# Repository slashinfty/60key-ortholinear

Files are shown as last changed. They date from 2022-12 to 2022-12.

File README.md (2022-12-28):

# 60key-ortholinear
A 5x12 ortholinear keyboard using a Raspberry Pi Pico

## Bill of Materials
* Case (see below)
* PCB (see below)
* Raspberry Pi Pico (with separate pin headers)
* 60 switches (I used Brown Gateron)
* 60 1N4148 diodes
* 60 1u keycaps

### Case
I have 3D designed a case specifically for this keyboard. It requires 4 M2.5x12mm screws.

### PCB
Gerber files have been uploaded to this repository, and a service such as JLCPCB can be used to order PCBs.

## Assembly
Complete these steps in order:
* Place the pin headers on the back, and apply solder on the front. Cut the excess flush with the PCB.
* Place diodes on the back, and apply solder on the front. Cut the excess flush with the PCB.
* Insert switches to the front of the case, mindful of orientation with the PCB.
* Place the PCB onto the switches, and apply solder on the back.
* Place the Raspberry Pi Pico on the pin headers and apply solder.
* Place the two halves of the case together and secure using screws.
* Place keycaps on switches.

## Code
First, [install CircuitPython](https://learn.adafruit.com/welcome-to-circuitpython/installing-circuitpython). Then, copy `keyboard.py` to the Raspberry Pi Pico.

The layout of the keyboard can be viewed [here](http://www.keyboard-layout-editor.com/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'%3B&@=Shift&=Z&=X&=C&=V&=B&=N&=M&_a:4%3B&=%0A%0A%0A-%0A%0A%0A%0A%0A%0A,&=%0A%0A%0A%2F=%0A%0A%0A%0A%0A%0A.&=%0A%0A%0A%5B%0A%0A%0A%0A%0A%0A%2F%2F&=%0A%0A%0A%5D%0A%0A%0A%0A%0A%0A%5C%3B&@_a:7%3B&=Prt%20Sc&=Ctrl&=Super&=Alt&=Fn%201&=&=&=Fn%202&_a:4%3B&=%0A%0A%0AH%0A%0A%0A%0A%0A%0A%2F&larr%2F%3B&=%0A%0A%0APD%0A%0A%0A%0A%0A%0A%2F&darr%2F%3B&=%0A%0A%0APU%0A%0A%0A%0A%0A%0A%2F&uarr%2F%3B&=%0A%0A%0AE%0A%0A%0A%0A%0A%0A%2F&rarr%2F).

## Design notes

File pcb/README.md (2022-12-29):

Raspberry Pi Pico KiCad files available [here](https://github.com/ncarandini/KiCad-RP-Pico).

Keyboard switch KiCad files available [here](https://github.com/perigoso/keyswitch-kicad-library).

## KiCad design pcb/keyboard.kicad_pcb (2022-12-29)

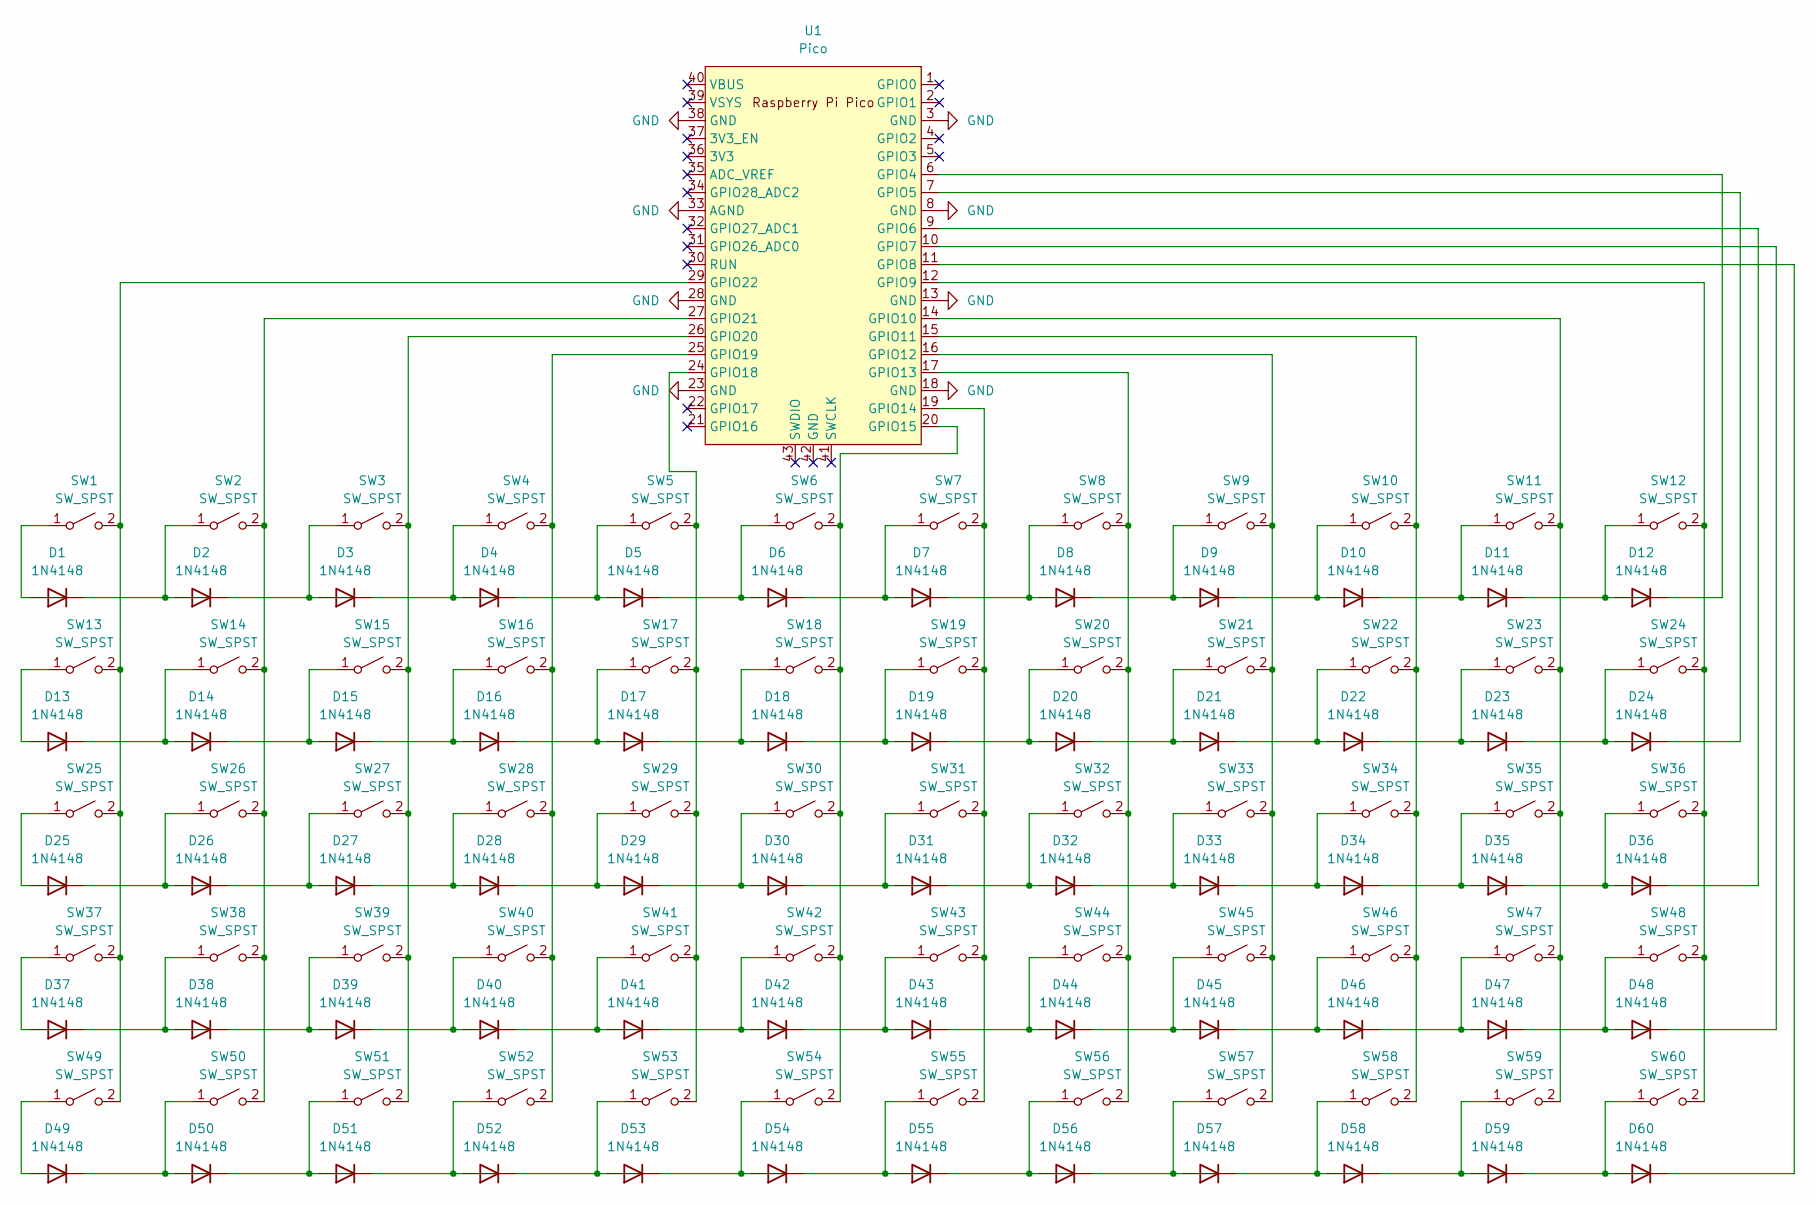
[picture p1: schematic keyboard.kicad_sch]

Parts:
D1, D2, D3, D4, D5, D6, D7, D8, D9, D10, D11, D12, D13, D14, D15, D16, D17, D18, D19, D20, D21, D22, D23, D24, D25, D26, D27, D28, D29, D30, D31, D32, D33, D34, D35, D36, D37, D38, D39, D40, D41, D42, D43, D44, D45, D46, D47, D48, D49, D50, D51, D52, D53, D54, D55, D56, D57, D58, D59, D60: 1N4148; D_DO-35_SOD27_P7.62mm_Horizontal
SW1, SW2, SW3, SW4, SW5, SW6, SW7, SW8, SW9, SW10, SW11, SW12, SW13, SW14, SW15, SW16, SW17, SW18, SW19, SW20, SW21, SW22, SW23, SW24, SW25, SW26, SW27, SW28, SW29, SW30, SW31, SW32, SW33, SW34, SW35, SW36, SW37, SW38, SW39, SW40, SW41, SW42, SW43, SW44, SW45, SW46, SW47, SW48, SW49, SW50, SW51, SW52, SW53, SW54, SW55, SW56, SW57, SW58, SW59, SW60: SW_SPST; SW_Cherry_MX_1.00u_Plate
U1: Pico; RPi_Pico_SMD_TH

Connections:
GND: U1.3 (GND), U1.8 (GND), U1.13 (GND), U1.18 (GND), U1.23 (GND), U1.28 (GND), U1.33 (AGND), U1.38 (GND)
unnamed: D1.1 (K), D2.2 (A), SW2.1 (A)
unnamed: D1.2 (A), SW1.1 (A)
unnamed: D2.1 (K), D3.2 (A), SW3.1 (A)
unnamed: D3.1 (K), D4.2 (A), SW4.1 (A)
unnamed: D4.1 (K), D5.2 (A), SW5.1 (A)
unnamed: D5.1 (K), D6.2 (A), SW6.1 (A)
unnamed: D6.1 (K), D7.2 (A), SW7.1 (A)
unnamed: D7.1 (K), D8.2 (A), SW8.1 (A)
unnamed: D8.1 (K), D9.2 (A), SW9.1 (A)
unnamed: D9.1 (K), D10.2 (A), SW10.1 (A)
unnamed: D10.1 (K), D11.2 (A), SW11.1 (A)
unnamed: D11.1 (K), D12.2 (A), SW12.1 (A)
unnamed: D12.1 (K), U1.6 (GPIO4)
unnamed: D13.1 (K), D14.2 (A), SW14.1 (A)
unnamed: D13.2 (A), SW13.1 (A)
unnamed: D14.1 (K), D15.2 (A), SW15.1 (A)
unnamed: D15.1 (K), D16.2 (A), SW16.1 (A)
unnamed: D16.1 (K), D17.2 (A), SW17.1 (A)
unnamed: D17.1 (K), D18.2 (A), SW18.1 (A)
unnamed: D18.1 (K), D19.2 (A), SW19.1 (A)
unnamed: D19.1 (K), D20.2 (A), SW20.1 (A)
unnamed: D20.1 (K), D21.2 (A), SW21.1 (A)
unnamed: D22.1 (K), D23.2 (A), SW23.1 (A)
unnamed: D21.1 (K), D22.2 (A), SW22.1 (A)
unnamed: D23.1 (K), D24.2 (A), SW24.1 (A)
unnamed: D24.1 (K), U1.7 (GPIO5)
unnamed: D25.1 (K), D26.2 (A), SW26.1 (A)
unnamed: D25.2 (A), SW25.1 (A)
unnamed: D26.1 (K), D27.2 (A), SW27.1 (A)
unnamed: D27.1 (K), D28.2 (A), SW28.1 (A)
unnamed: D28.1 (K), D29.2 (A), SW29.1 (A)
unnamed: D29.1 (K), D30.2 (A), SW30.1 (A)
unnamed: D30.1 (K), D31.2 (A), SW31.1 (A)
unnamed: D31.1 (K), D32.2 (A), SW32.1 (A)
unnamed: D32.1 (K), D33.2 (A), SW33.1 (A)
unnamed: D33.1 (K), D34.2 (A), SW34.1 (A)
unnamed: D34.1 (K), D35.2 (A), SW35.1 (A)
unnamed: D35.1 (K), D36.2 (A), SW36.1 (A)
unnamed: D36.1 (K), U1.9 (GPIO6)
unnamed: D37.1 (K), D38.2 (A), SW38.1 (A)
unnamed: D37.2 (A), SW37.1 (A)
unnamed: D38.1 (K), D39.2 (A), SW39.1 (A)
unnamed: D39.1 (K), D40.2 (A), SW40.1 (A)
unnamed: D40.1 (K), D41.2 (A), SW41.1 (A)
unnamed: D41.1 (K), D42.2 (A), SW42.1 (A)
unnamed: D42.1 (K), D43.2 (A), SW43.1 (A)
unnamed: D43.1 (K), D44.2 (A), SW44.1 (A)
unnamed: D44.1 (K), D45.2 (A), SW45.1 (A)
unnamed: D45.1 (K), D46.2 (A), SW46.1 (A)
unnamed: D46.1 (K), D47.2 (A), SW47.1 (A)
unnamed: D47.1 (K), D48.2 (A), SW48.1 (A)
unnamed: D48.1 (K), U1.10 (GPIO7)
unnamed: D49.1 (K), D50.2 (A), SW50.1 (A)
unnamed: D50.1 (K), D51.2 (A), SW51.1 (A)
unnamed: D51.1 (K), D52.2 (A), SW52.1 (A)
unnamed: D52.1 (K), D53.2 (A), SW53.1 (A)
unnamed: D53.1 (K), D54.2 (A), SW54.1 (A)
unnamed: D54.1 (K), D55.2 (A), SW55.1 (A)
unnamed: D55.1 (K), D56.2 (A), SW56.1 (A)
unnamed: D56.1 (K), D57.2 (A), SW57.1 (A)
unnamed: D57.1 (K), D58.2 (A), SW58.1 (A)
unnamed: D58.1 (K), D59.2 (A), SW59.1 (A)
unnamed: D59.1 (K), D60.2 (A), SW60.1 (A)
unnamed: D60.1 (K), U1.11 (GPIO8)
unnamed: SW1.2 (B), SW13.2 (B), SW25.2 (B), SW37.2 (B), SW49.2 (B), U1.29 (GPIO22)
unnamed: SW2.2 (B), SW14.2 (B), SW26.2 (B), SW38.2 (B), SW50.2 (B), U1.27 (GPIO21)
unnamed: SW3.2 (B), SW15.2 (B), SW27.2 (B), SW39.2 (B), SW51.2 (B), U1.26 (GPIO20)
unnamed: SW4.2 (B), SW16.2 (B), SW28.2 (B), SW40.2 (B), SW52.2 (B), U1.25 (GPIO19)
unnamed: SW9.2 (B), SW21.2 (B), SW33.2 (B), SW45.2 (B), SW57.2 (B), U1.16 (GPIO12)
unnamed: SW10.2 (B), SW22.2 (B), SW34.2 (B), SW46.2 (B), SW58.2 (B), U1.15 (GPIO11)
unnamed: SW11.2 (B), SW23.2 (B), SW35.2 (B), SW47.2 (B), SW59.2 (B), U1.14 (GPIO10)
unnamed: SW12.2 (B), SW24.2 (B), SW36.2 (B), SW48.2 (B), SW60.2 (B), U1.12 (GPIO9)
unnamed: SW6.2 (B), SW18.2 (B), SW30.2 (B), SW42.2 (B), SW54.2 (B), U1.20 (GPIO15)
unnamed: SW7.2 (B), SW19.2 (B), SW31.2 (B), SW43.2 (B), SW55.2 (B), U1.19 (GPIO14)
unnamed: SW8.2 (B), SW20.2 (B), SW32.2 (B), SW44.2 (B), SW56.2 (B), U1.17 (GPIO13)
unnamed: D49.2 (A), SW49.1 (A)
unnamed: SW5.2 (B), SW17.2 (B), SW29.2 (B), SW41.2 (B), SW53.2 (B), U1.24 (GPIO18)

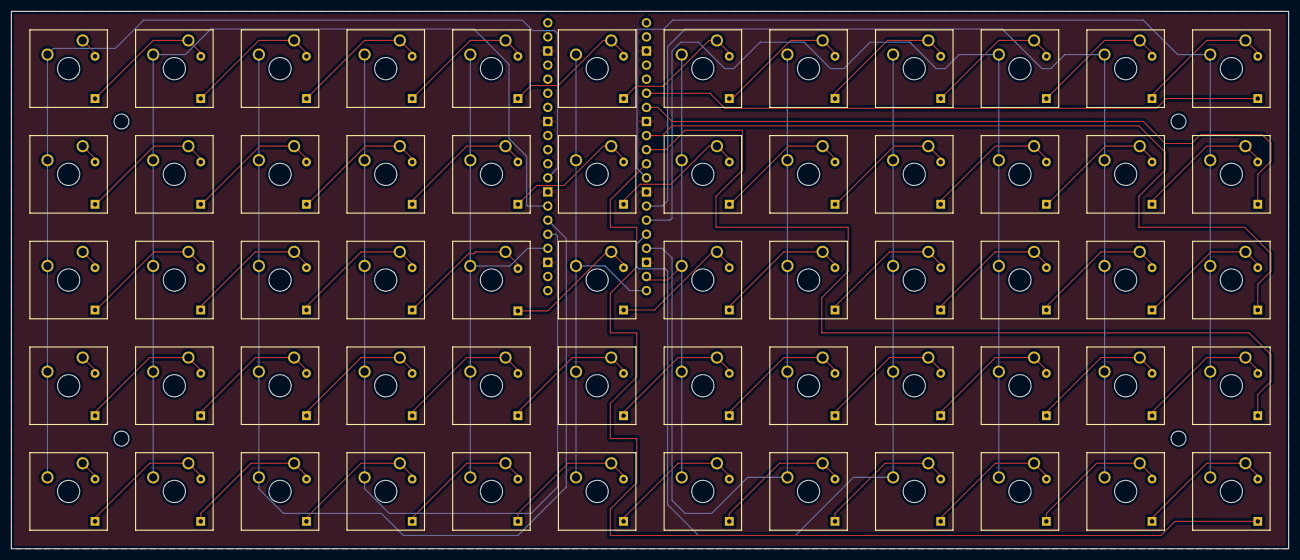
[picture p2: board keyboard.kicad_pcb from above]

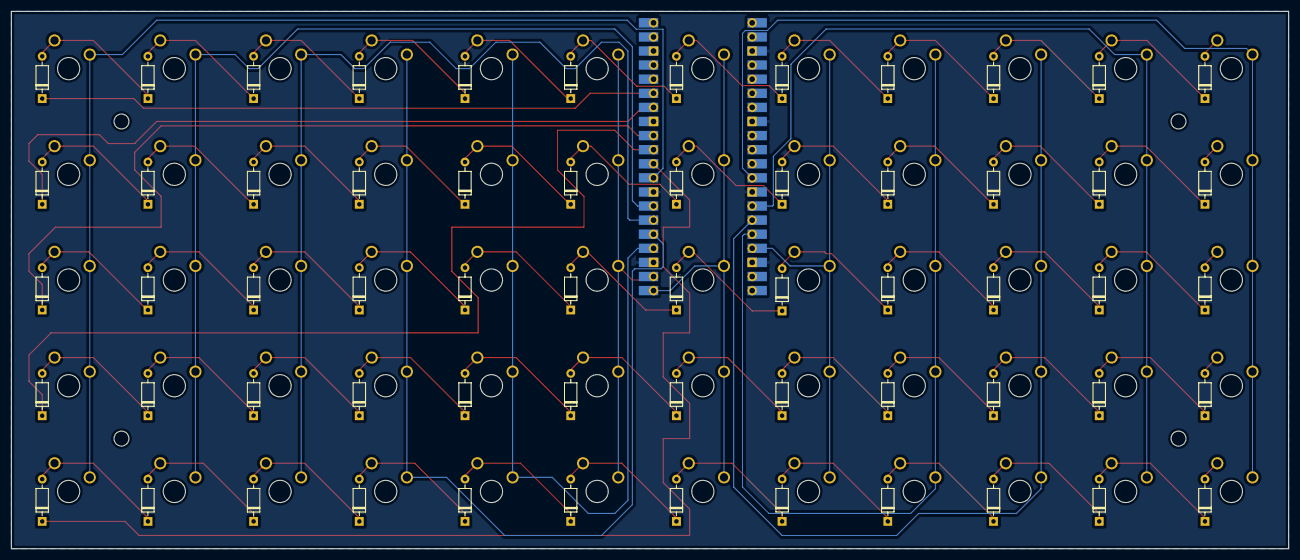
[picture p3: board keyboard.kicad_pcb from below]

Board: 2 copper layers, 230.2 x 96.8 mm, 121 parts (61 on the bottom side), 78 nets.
